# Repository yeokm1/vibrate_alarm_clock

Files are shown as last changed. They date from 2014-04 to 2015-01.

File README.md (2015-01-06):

vibrate_alarm_clock
===================

An alarm clock with vibration and battery monitoring capabilities. During an alarm, it plays the Super Mario tune. Buttons available to set the alarm, turn off OLED and reset. This device is meant for my friend's birthday gift.

The second iteration of this clock can be found [here](https://github.com/yeokm1/vibrate_alarm_clock_2).

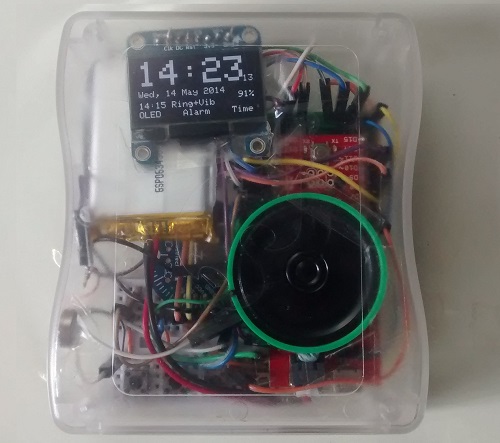
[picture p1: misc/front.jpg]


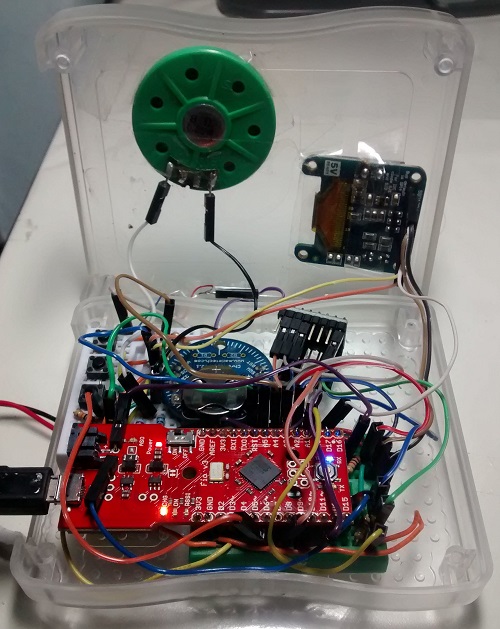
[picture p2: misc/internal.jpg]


I agree this is an epic mess but the space constraints left me no choice. Higher resolution photos are available in the "misc" directory. Battery life is approximately 60 hours based on usage of 16mA with alarm disabled or 38 hours of 26mA with alarm enabled. If the OLED is left on constantly, power use increases to 32mA reducing battery life to 31 hours.  
(See Tips point 3).

<b>Main Parts used:</b>  

1. Sparkfun Arduino Fio V3 (based on ATmega32U4 chip)  
2. Adafruit 1.3" 128x64 OLED set to I2C  
3. Chronodot v2.1 Real Time Clock (based on DS3231 temperature compensated RTC crystal)  
4. 4x button switches (1 switch as reset button)  
5. 3x 10k ohm resistors (for switches)  
6. 8 ohm thin speaker  
7. 100 ohm resistor (for speaker)  
8. 2x 1Mega ohm resistors (as voltage divider to measure battery voltage)
9. Pololu DRV8833 dual motor driver  
10. 10mm vibration motor
11. 1000mAh Lithium battery

Optional:  

1. 2x half-breadboard 
2. Translucent case  

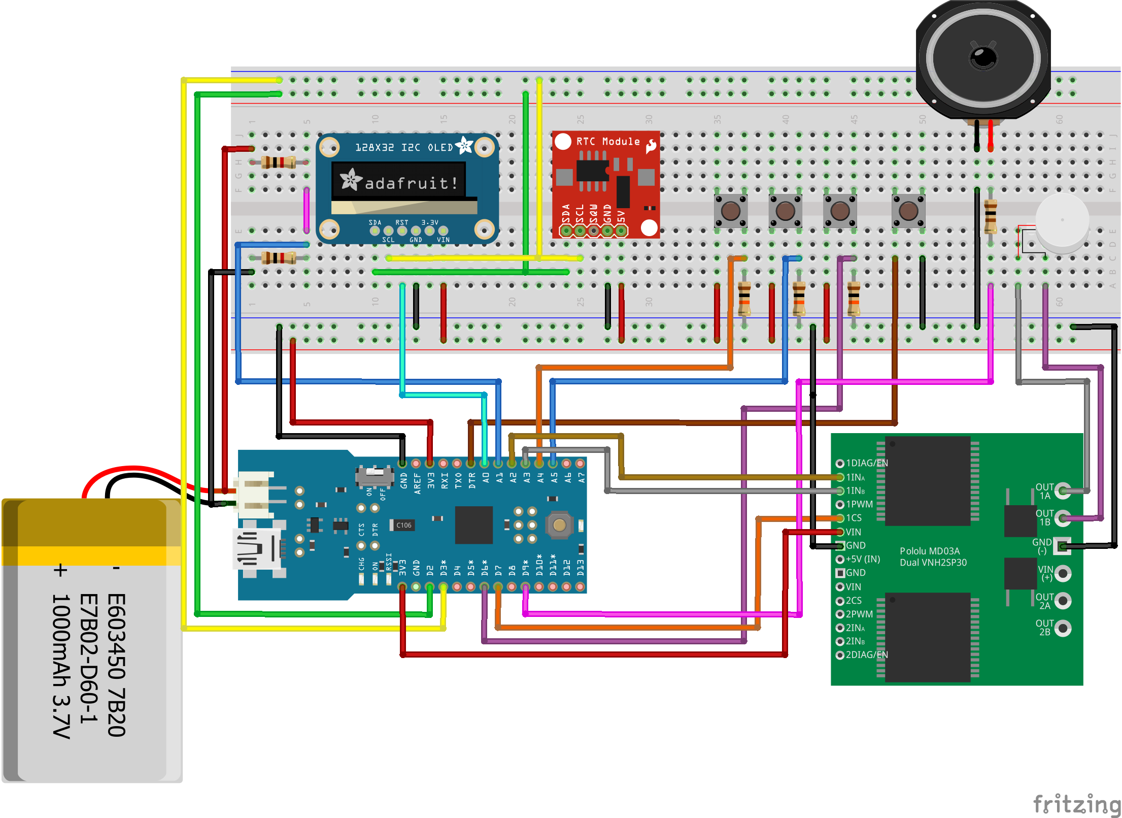
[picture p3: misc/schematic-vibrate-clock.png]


This schematic only represents the logical connections I made. The physical connections differs due to space issues.   
Closest components used as Fritzing does not have them.  
1. MD030A as DRV8833 motor driver. (Pin D7 on the Arduino is connected to the sleep pin on the DRV8833.)  
2. 128x32 OLED as 128x64 OLED.  
3. Fio as Fio V3 (Fio's DTR Pin = Fio V3's RST Pin)  
4. RTC module as Chronodot

<b>Tips:</b>

1. Try to avoid using float variables in your Arduino code if you are tight on binary size. Use integer or long types for intermediate variables if you can.

2. Store unimportant data into flash memory to reduce SRAM usage.

3. Using Rocket Scream's Low Power library works wonders on the Arduino power usage. Standby current use with OLED off is reduced from 26mA to 16mA giving battery life at approximately 60 hours under best case scenario. This advantage disappears once the alarm is enabled. The low power mode somehow prevents the alarm from activating so I have no choice but to disable the low power mode whenever ring or vibrate is enabled. 

<b>Stuff to note:</b>

1. It is possible to set a wrong date and time to the Chronodot. The Chronodot seems to just freeze there? I can check for everything except for the number of days in a month. The extra code to do this check is too much to put into the limited space of the Fio V3. So do be careful when setting the date component.  

2. Included is a subproject named vibrate_alarm_clock_test. This is meant to test all input and output functions.  
  a. On startup, the motor will briefly turn in one then the opposite direction.  
  b. Speaker will play a short tune.  
  c. Pressing first button will rotate motor in one direction until released.  
  d. Pressing second button will rotate motor in another direction until released.  
  e. Pressing both first and second buttons will play the short tune.  
  f. Third button will turn on/off the OLED.  
  g. Since the Arduino IDE only allows included header files to be in the same directory as the .ino, I had to duplicate the constants.h and pitches.h twice. Otherwise, they should be identical and shared between the sub and actual project.

3. The Arduino Fio V3 is quite a finicky thing. Occasionally it will repeatedly refuse to accept code uploads and just disconnect the USB connection. Unplugging/Replugging the USB cable even to another USB port does not work. Pressing the reset button three times before an upload seems to make it work again.

4. The OLED is set by default to use the SPI interface. If you want to use I2C, remember to solder the jumpers at the back. I used I2C to reduce the wire clutter since Chronodot already uses I2C.

5. The OLED library supplied by Adafruit requires at least 1K RAM on the Arduino to buffer the display. The Fio V3 only has 2K so that leaves 1K for other tasks. If you use too much RAM, the OLED may behave strangely like some parts not "rendered".  

6. Super Mario tune is contained in the tune.h header file. To save memory, the tune is stored into flash memory via PROGMEM to minimise SRAM usage.

7. I actually used 2x 220ohm resistors as I did not have a 100ohm resistor. I connected those in parallel to give approximately 100ohm for the speaker.

8. One is supposed to add a pull-up resistor for the I2C bus lines SCL and SDA if more than one device (OLED and Chronodot) uses them. I tried without the resistor and it seems to work fine. 

9. Fio V3's I2C lines are on D2(SDA) and D3(SCL).  

10. The alarm by default lasts for only 10 minutes before automatically turning off to conserve power. Customise this value MAX_ALARM_LENGTH if needed.  

<b>References and libraries:</b>  

1. Adafruit SSD1306 OLED library  
(https://github.com/adafruit/Adafruit_SSD1306)

2. AnyRTC RTClib    
(https://github.com/maniacbug/AnyRtc)

3. Rocket Scream Low Power library  
(http://www.rocketscream.com/blog/2011/07/04/lightweight-low-power-arduino-library/)

4. Get day of week from date.  
(http://stackoverflow.com/a/21235587)

5. Super Mario tune  
(http://www.linuxcircle.com/2013/03/31/playing-mario-bros-tune-with-arduino-and-piezo-buzzer/)

The MIT License (MIT)<br>
Copyright (c) 2014-2014 Yeo Kheng Meng<br>

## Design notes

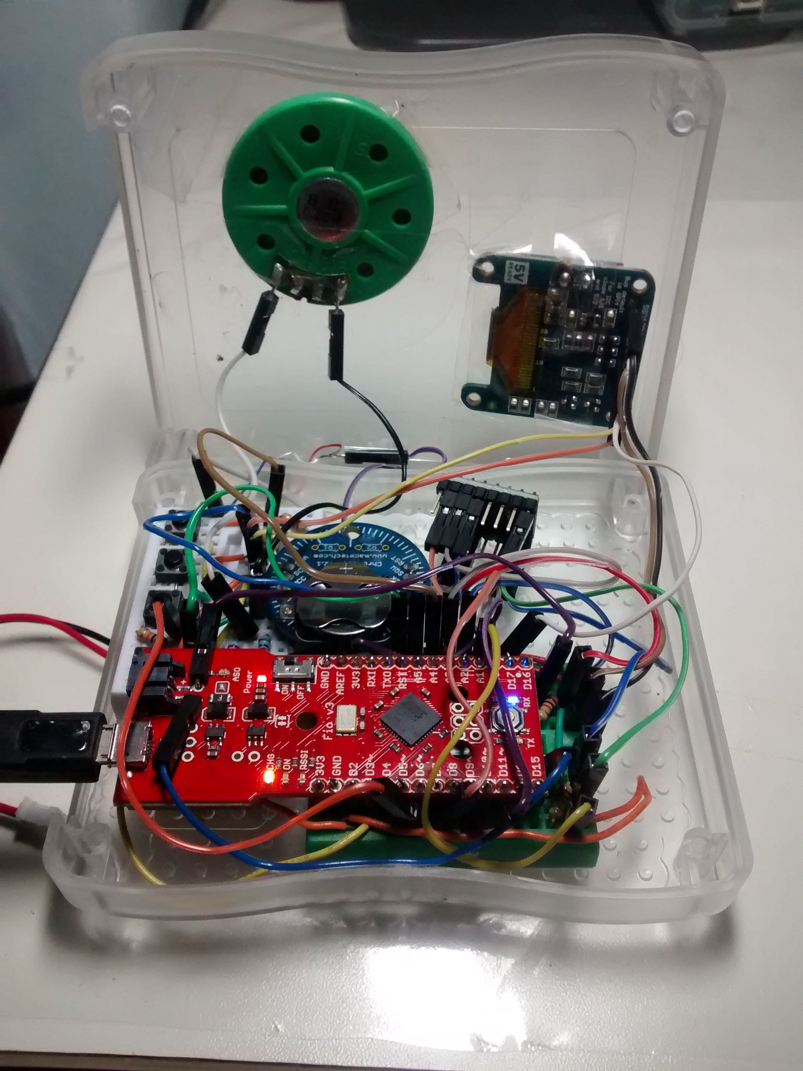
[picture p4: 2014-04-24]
misc/internal-original.jpg

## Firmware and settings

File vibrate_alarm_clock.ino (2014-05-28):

#include <Wire.h>
#include <SPI.h>
#include <Adafruit_GFX.h>
#include <Adafruit_SSD1306.h>
#include <RTClib.h>
#include <RTC_DS1307.h>

#include "LowPower.h"
#include "constants.h"
#include "tune.h"

#define DO_NOT_SHOW_SERIAL_OUT //Comment this line if you want serial debugging for button press

#define MIN_BATTERY_MILLIVOLT 3350 //You may need to calibrate this
#define MAX_BATTERY_MILLIVOLT 4200 //You may need to calibrate this

#define DISPLAY_CONTRAST true

#define INITIAL_TEXT "Happy 24th birthday\n Jason!\n\nBy: Yeo Kheng Meng\n(14 May 2014)"
#define INITIAL_TEXT_DELAY 5000
#define MIN_TIME_BETWEEN_BUTTON_PRESSES 100  //Debouncing purposes
#define BLINK_INTERVAL 100



#define MIN_TIME_BETWEEN_ALARM_STARTS 60000 //60 seconds
#define MIN_TIME_TO_CHANGE_MOTOR_DIRECTION 500

#define MAX_ALARM_LENGTH 600000 //Alarm rings for 10 minutes max

RTC_DS1307 RTC;
Adafruit_SSD1306 display(OLED_RESET_PIN);

typedef enum {NORMAL, ALARM, SETTING_TIME, SETTING_ALARM} CLOCK_STATE ;
CLOCK_STATE currentState = NORMAL;

typedef enum {T_HOUR, T_MINUTE, T_SECOND, T_DAY, T_MONTH, T_YEAR} SETTING_TIME_STATE ;
SETTING_TIME_STATE settingTimeProcess;

typedef enum {A_HOUR, A_MINUTE, A_TYPE} SETTING_ALARM_STATE ;
SETTING_ALARM_STATE settingAlarmProcess;

boolean alarmVibrate = false;
boolean alarmSound = false;

int alarmHour = 07;
int alarmMinute = 00;

unsigned long alarmLastStarted;

typedef enum{M_CLOCKWISE, M_PAUSE} MOTOR_STATE;
MOTOR_STATE lastMotorState;

unsigned long lastVibration;

unsigned long timeLastPressedLeftButton;
unsigned long timeLastPressedMiddleButton;
unsigned long timeLastPressedRightButton;


boolean previousBlinkState;
unsigned long previousBlinkTime;


unsigned long timePlayedPreviousTone;
int toneNow = 0;
int previousNoteDuration;
  
boolean showLCD = true;

void setup(){

  #ifndef DO_NOT_SHOW_SERIAL_OUT
    Serial.begin(9600);
  #endif
  
 //Turn off TX and RX pin
  pinMode(RXLED_PIN, OUTPUT);
  digitalWrite(RXLED_PIN, LOW);
  TXLED1;
  
  Wire.begin();
  RTC.begin();
  

  // This section grabs the current datetime and compares it to
  // the compilation time.  If necessary, the RTC is updated.
  DateTime now = RTC.now();
  DateTime compiled = DateTime(__DATE__, __TIME__);
  
  if (now.unixtime() < compiled.unixtime()) {
    RTC.adjust(DateTime(__DATE__, __TIME__));
  } 
  
  
  // initialize with the OLED with I2C addr 0x3D (for the 128x64)
  display.begin(SSD1306_SWITCHCAPVCC, 0x3D); 
  
  display.dim(DISPLAY_CONTRAST);
  
  display.clearDisplay();
  display.setTextColor(WHITE);
  display.setTextSize(1);
  display.setCursor(0,0);
  display.println(INITIAL_TEXT);
 
  
  display.display();
  
  
  delay(INITIAL_TEXT_DELAY);
  

  pinMode(LEFT_BUTTON_PIN, INPUT); 
  pinMode(MIDDLE_BUTTON_PIN, INPUT); 
  pinMode(RIGHT_BUTTON_PIN, INPUT);
  pinMode(VOLTAGE_MEASURE_PIN, INPUT);
  
  pinMode(MOTOR_PIN1, OUTPUT); 
  pinMode(MOTOR_PIN2, OUTPUT);
  pinMode(MOTOR_SLEEP_PIN, OUTPUT);
  
}


void loop(){
   
 
  int leftButtonState = digitalRead(LEFT_BUTTON_PIN);
  int middleButtonState = digitalRead(MIDDLE_BUTTON_PIN);
  int rightPinState = digitalRead(RIGHT_BUTTON_PIN);

  if(leftButtonState == HIGH){
    processLeftButtonPressed();
  }
  
  if(middleButtonState == HIGH){
    processMiddleButtonPressed();
  }
  
  if(rightPinState == HIGH){
    processRightButtonPressed();
  }
 
  DateTime now = RTC.now();
  

  checkAndSoundAlarm(now.hour(), now.minute());
  soundAlarmAtThisPointIfNeeded();
  
  //Disable alarm if it has gone longer than maximum
  if(currentState == ALARM && (millis() - alarmLastStarted) > MAX_ALARM_LENGTH){
    stopAlarm();
  }
  
  if(showLCD || currentState == ALARM){
    
    display.clearDisplay();

    boolean blinkOn = shouldBlinkNow();
    
   
    int voltageADCReading = analogRead(VOLTAGE_MEASURE_PIN);
     //Multiply 2 as we are are using a half voltage divider
    int batteryMilliVolt = ((long) voltageADCReading * 2 * VOLTAGE_OF_VCC_MV) / ADC_PRECISION;

    writeDateTimeToDisplayBuffer(now, blinkOn);
    writeAlarmToDisplayBuffer(blinkOn);
    writeVoltageToDisplayBuffer(batteryMilliVolt);
    writeButtonStateToDisplayBuffer(blinkOn);
    
    
    display.display();
  }
  
  if((currentState == NORMAL)
  && !alarmSound && !alarmVibrate){
    //Only sleep if no alarm is set. If in other modes like setting, give max performance. 
     LowPower.powerDown(SLEEP_30MS, ADC_OFF, BOD_OFF);

  }
  
}
 
void processLeftButtonPressed(){
  unsigned long currentMillis = millis();
  
  if((currentMillis - timeLastPressedLeftButton) < MIN_TIME_BETWEEN_BUTTON_PRESSES){
    return;
  }
  
  timeLastPressedLeftButton = currentMillis;
  

 #ifndef DO_NOT_SHOW_SERIAL_OUT
   Serial.println("Left Button Press");
 #endif
 
 
  switch(currentState)
  {
  case ALARM: stopAlarm();
  break;
  case NORMAL :
  {
    showLCD = !showLCD;
    turnOffLCD();
    
  }
  break;
  case SETTING_ALARM:
  {
   if(settingAlarmProcess == A_HOUR){
       alarmHour = getNextHourFromCurrentHour(alarmHour, false);
    } else if(settingAlarmProcess == A_MINUTE){
       alarmMinute = getNextMinSecFromCurrentMinSec(alarmMinute, false);
    } else if(settingAlarmProcess == A_TYPE){
              
       if(!alarmVibrate && !alarmSound){
            //Both off, turn on sound
          alarmVibrate = true;
          alarmSound = true;
       } else if(!alarmVibrate && alarmSound){
          //Vibrate off, alarm on, turn on vibrate only
          alarmVibrate = false;
          alarmSound = false;
       } else if(alarmVibrate && !alarmSound){
         //Vibrate on, alarm off, turn on both
         alarmVibrate = false;
         alarmSound = true;  
       } else {
          //Both are on, turn both off
          alarmVibrate = true;
          alarmSound = false;  
      }
   }
  
  }
  break;
  case SETTING_TIME:
  {
    DateTime now = RTC.now();
    DateTime newTime;
    switch(settingTimeProcess){
      case T_HOUR:
        newTime = DateTime(now.year(), now.month(), now.day(), getNextHourFromCurrentHour(now.hour(), false), now.minute(), now.second());
        break;
      case T_MINUTE:
        newTime = DateTime(now.year(), now.month(), now.day(), now.hour(), getNextMinSecFromCurrentMinSec(now.minute(), false), now.second());
        break;
      case T_SECOND:
        newTime = DateTime(now.year(), now.month(), now.day(), now.hour(), now.minute(), getNextMinSecFromCurrentMinSec(now.second(), false));
        break;
      case T_DAY:
        newTime = DateTime(now.year(), now.month(), now.day() - 1, now.hour(), now.minute(), now.second());
        break;
      case T_MONTH:
      {
        int month = now.month();
        if(month == 1){
          month = 12;
        } else {
          month--;
        }
      
        newTime = DateTime(now.year(), month, now.day(), now.hour(), now.minute(), now.second());
      }
        break;
      case T_YEAR:
        newTime = DateTime(now.year() - 1, now.month(), now.day(), now.hour(), now.minute(), now.second());
        break;
      default: break;
     
    }
       
    RTC.adjust(newTime);
  }
  break;
  default: break;
  }
  
  
}

void processMiddleButtonPressed(){
  unsigned long currentMillis = millis();
  

  if((currentMillis - timeLastPressedMiddleButton) < MIN_TIME_BETWEEN_BUTTON_PRESSES){
    return;
  }
  
  timeLastPressedMiddleButton = currentMillis;

 #ifndef DO_NOT_SHOW_SERIAL_OUT
   Serial.println("Middle Button Pressed");
 #endif
   
  switch(currentState)
  {
    case ALARM: stopAlarm();
    break;
    case NORMAL :
    {
      if(showLCD){
        currentState = SETTING_ALARM;
        settingAlarmProcess = A_HOUR;
      } else {
        showLCD = true;
      }

    }
    break;
    case SETTING_ALARM:
    {
      if(settingAlarmProcess == A_HOUR){
         settingAlarmProcess = A_MINUTE;
      } else if(settingAlarmProcess == A_MINUTE){
         settingAlarmProcess = A_TYPE;
      } else {
        currentState = NORMAL;
      }

    }
    break;
    case SETTING_TIME:
    {
      if(settingTimeProcess == T_HOUR){
         settingTimeProcess = T_MINUTE;
      } else if(settingTimeProcess == T_MINUTE){
         settingTimeProcess = T_SECOND;
      } else if(settingTimeProcess == T_SECOND){
         settingTimeProcess = T_DAY;      
      } else if(settingTimeProcess == T_DAY){
        settingTimeProcess = T_MONTH; 
      } else if(settingTimeProcess == T_MONTH){
         settingTimeProcess = T_YEAR;           
      } else {
        currentState = NORMAL;
      }
      
    }
    break;
    default: break;
    }
  


}


void processRightButtonPressed(){
  
  unsigned long currentMillis = millis();
  

  if((currentMillis - timeLastPressedRightButton) < MIN_TIME_BETWEEN_BUTTON_PRESSES){
    return;
  }
   
  timeLastPressedRightButton = currentMillis;

  #ifndef DO_NOT_SHOW_SERIAL_OUT
   Serial.println("Right Set Button Pressed");
  #endif
   
  switch(currentState)
  {
    case ALARM: stopAlarm();
    break;
    case NORMAL :
   { 
      if(showLCD){
        currentState = SETTING_TIME;
        settingTimeProcess = T_HOUR;
      } else {
        showLCD = true;
      }
      
   }
    break;
    case SETTING_ALARM:
    {
        if(settingAlarmProcess == A_HOUR){
          alarmHour = getNextHourFromCurrentHour(alarmHour, true);
        } else if(settingAlarmProcess == A_MINUTE){
          alarmMinute = getNextMinSecFromCurrentMinSec(alarmMinute, true);
        } else if(settingAlarmProcess == A_TYPE){
              
          if(!alarmVibrate && !alarmSound){
                //Both off, turn on sound
                alarmVibrate = false;
                alarmSound = true;
              } else if(!alarmVibrate && alarmSound){
                //Vibrate off, alarm on, turn on vibrate only
                alarmVibrate = true;
                alarmSound = false;
              } else if(alarmVibrate && !alarmSound){
              //Vibrate on, alarm off, turn on both
                alarmVibrate = true;
                alarmSound = true;  
              } else {
                //Both are on, turn both off
                alarmVibrate = false;
                alarmSound = false;  
              }
        }
    }
    break;
    case SETTING_TIME:
      {
    DateTime now = RTC.now();
    DateTime newTime;
    switch(settingTimeProcess){
      case T_HOUR:
        newTime = DateTime(now.year(), now.month(), now.day(), getNextHourFromCurrentHour(now.hour(), true), now.minute(), now.second());
        break;
      case T_MINUTE:
        newTime = DateTime(now.year(), now.month(), now.day(), now.hour(), getNextMinSecFromCurrentMinSec(now.minute(), true), now.second());
        break;
      case T_SECOND:
        newTime = DateTime(now.year(), now.month(), now.day(), now.hour(), now.minute(), getNextMinSecFromCurrentMinSec(now.second(), true));
        break;
      case T_DAY:
        newTime = DateTime(now.year(), now.month(), now.day() + 1, now.hour(), now.minute(), now.second());
        break;
      case T_MONTH:
      {
        int month = now.month();
        if(month == 12){
          month = 1;
        } else {
          month++;
        }
        newTime = DateTime(now.year(), month, now.day(), now.hour(), now.minute(), now.second());
      }
        break;
      case T_YEAR:
        newTime = DateTime(now.year() + 1, now.month(), now.day(), now.hour(), now.minute(), now.second());
        break;
      default: break;
     
    }
       
    RTC.adjust(newTime);
  }
    
    
    break;
    default: break;
  }

}


void writeButtonStateToDisplayBuffer(boolean blinkOn){
  
  String buttonFunction;
  switch(currentState)
  {
    case ALARM: 
    {
      if(!blinkOn){
        buttonFunction = "Stop     Stop    Stop";
      }
    
    }
    break;
    case NORMAL : buttonFunction =  "OLED    Alarm    Time";
    break;
    case SETTING_ALARM: 
    //Fallthrough
    case SETTING_TIME: buttonFunction = "--       Next      ++";
    break;
    default: break;
  }
  
  display.setCursor(0,57);
  display.print(buttonFunction);
 
}


void writeVoltageToDisplayBuffer(int batteryMilliVolt){
  
  display.setTextSize(1);

//  float voltage = (float) batteryMilliVolt / 1000;
  
//  char buff[5];
//  String voltageString = dtostrf(voltage, 3, 1, buff);
// 
//  display.setCursor(104,49);
//  display.print(voltageString);
//  display.print("V");
  
  int batteryRange = MAX_BATTERY_MILLIVOLT - MIN_BATTERY_MILLIVOLT;

  //Cast to long as Arduino int is only 16 bits wide. Not enough to hold this result
  long numerator =  ((long) ((batteryMilliVolt - MIN_BATTERY_MILLIVOLT))) * 100;
  int batteryPercent = numerator / batteryRange;

  if(batteryPercent < 100){
     display.setCursor(110,40);
  } else {
     display.setCursor(104,40);
  }
  display.print(batteryPercent);
  display.print("%");


}

void checkAndSoundAlarm(int hour, int minute){
  
  unsigned long currentMillis = millis();
  
  
  
  if(hour == alarmHour && minute == alarmMinute && currentState == NORMAL
  && ((currentMillis - alarmLastStarted) > MIN_TIME_BETWEEN_ALARM_STARTS)
  && (alarmVibrate || alarmSound)){
    currentState = ALARM;
    alarmLastStarted = currentMillis;
   
   
     if(alarmVibrate){
        lastMotorState = M_CLOCKWISE;
        motorDriverState(true);
     }
  }

}


void soundAlarmAtThisPointIfNeeded(){

  if(currentState == ALARM){
    
    unsigned long currentMillis = millis();

    if(alarmVibrate && ((currentMillis - lastVibration) > MIN_TIME_TO_CHANGE_MOTOR_DIRECTION)){
      lastVibration = currentMillis;
      
      if(lastMotorState == M_CLOCKWISE){
        
        lastMotorState = M_PAUSE;
        changeMotorState(false, false);
      
      } else if(lastMotorState == M_PAUSE){
        
        lastMotorState = M_CLOCKWISE;
        changeMotorState(true, false);
      
      }


    }
    
    if(alarmSound && ((currentMillis - timePlayedPreviousTone) >  previousNoteDuration)){
      timePlayedPreviousTone = currentMillis;
      toneNow++;
      toneNow %= NUM_TONES;
      int noteDuration = 1000/getDurationAtThisPosition(toneNow);
      
      // to distinguish the notes, set a minimum time between them.
      // the note's duration + 30% seems to work well:
      previousNoteDuration = noteDuration * 1.3;
      tone(SPEAKER_PIN, getToneAtThisPosition(toneNow),noteDuration);
      
    }

  }
  
}

void turnOffLCD(){
  if(!showLCD){
    display.clearDisplay();
    display.display();
  }
}

void stopAlarm(){
  currentState = NORMAL;
  motorDriverState(false);
  noTone(SPEAKER_PIN);
  toneNow = 0;
  
  turnOffLCD();
  
}


void writeAlarmToDisplayBuffer(boolean blinkOn){
    
    char buff[3];

    String alarmHourString;
    
    if(currentState == SETTING_ALARM && settingAlarmProcess == A_HOUR && !blinkOn){
     //Now setting this, do not show 
     alarmHourString = "  ";
    } else {
      sprintf(buff, "%02d", alarmHour);
      alarmHourString = buff;
    }
    
    String alarmMinuteString;
    
    if(currentState == SETTING_ALARM && settingAlarmProcess == A_MINUTE && !blinkOn){
     //Now setting this, do not show 
     alarmMinuteString = "  ";
    } else {
      sprintf(buff, "%02d", alarmMinute);
      alarmMinuteString = buff;
    }

    String alarmTimeString;
    String alarmSetting;
       
    if(currentState == SETTING_ALARM && settingAlarmProcess == A_TYPE && !blinkOn){
     //Now setting this, do not show 
     alarmSetting = "";
    } else {
     if(alarmVibrate && alarmSound){
          alarmSetting = " Ring+Vib"; 
      } else if(alarmVibrate){
          alarmSetting = " Vibrate"; 
      } else if(alarmSound){
          alarmSetting = " Ring"; 
      } else {
        alarmSetting = " Alarm Off";
      }
     }

      alarmTimeString = alarmHourString + ":" + alarmMinuteString + alarmSetting;
    
    
    
    
    display.setCursor(0,47);
    display.println(alarmTimeString);

}

void writeDateTimeToDisplayBuffer(DateTime now, boolean blinkOn){
  display.setTextSize(4);
  display.setCursor(0,0);
  String timeString = generateTimeString(now.hour(), now.minute(), now.second(), blinkOn);
  display.print(timeString);
  
  char buff[3];


  if(!(currentState == SETTING_TIME && settingTimeProcess == T_SECOND && !blinkOn)){
    display.setCursor(116,22);
    sprintf(buff, "%02d", now.second());
    display.setTextSize(1);
    display.println(buff);
  }
  

  display.setCursor(0,34);
  display.setTextSize(1);
  String dateString = generateDateString(now.year(), now.month(), now.day(), blinkOn);
  display.println(dateString);

}



String generateTimeString(int hour, int minute, int second, boolean blinkOn){
  char buff[3];
  
  String hourString;
  
  if(currentState == SETTING_TIME && settingTimeProcess == T_HOUR && !blinkOn){
    hourString = "  ";
  } else {
    sprintf(buff, "%02d", hour);
    hourString = buff;
  }

  String minuteString;
  if(currentState == SETTING_TIME && settingTimeProcess == T_MINUTE && !blinkOn){
    minuteString = "  ";
  } else {
    sprintf(buff, "%02d", minute);
    minuteString = buff;
  }


  String result = hourString + ":" + minuteString;

  return result;
}

String generateDateString(int year, int month, int day, boolean blinkOn)
{
  String dayOfWeek = getDayOfTheWeek(year, month, day);
  String dayString;
  String monthString;
  String yearString;
  
  
  if(currentState == SETTING_TIME && settingTimeProcess == T_DAY && !blinkOn){
    dayString = "  ";
  } else {
    char buff[3];
    sprintf(buff, "%02d", day);
    dayString = buff;
  }
  
  if(currentState == SETTING_TIME && settingTimeProcess == T_MONTH && !blinkOn){
    monthString = "   ";
  } else {
    monthString = getMonth(month);
  }
  
  if(currentState == SETTING_TIME && settingTimeProcess == T_YEAR && !blinkOn){
    yearString = "    ";
  } else {
    yearString = String(year);
  }
  
  
 
  String result = dayOfWeek + ", " + dayString + " " + monthString + " " + yearString;
  
  return result;
}

// From http://stackoverflow.com/a/21235587
String getDayOfTheWeek(int y, int m, int d) {
  String weekdayname[] = {"Sun", "Mon", "Tue",
  "Wed", "Thu", "Fri", "Sat"};

  int weekday = (d+=m<3?y--:y-2,23*m/9+d+4+y/4-y/100+y/400)%7;
  
  
  return weekdayname[weekday];
}


String getMonth(int month){
  switch(month){
    case 1: return "Jan";
    case 2: return "Feb";
    case 3: return "Mar";
    
    case 4: return "Apr";
    case 5: return "May";
    case 6: return "Jun";
    
    case 7: return "Jul";
    case 8: return "Aug";
    case 9: return "Sep";
    
    case 10: return "Oct";
    case 11: return "Nov";
    case 12: return "Dec";
    default : return "Nil";
  }
}

void motorDriverState(boolean state){
  if(state){
    digitalWrite(MOTOR_SLEEP_PIN, HIGH);
  } else {
    digitalWrite(MOTOR_SLEEP_PIN, LOW);
  }
}

void changeMotorState(boolean active, bool direction){

  if(!active){
     digitalWrite(MOTOR_PIN1, LOW);
     digitalWrite(MOTOR_PIN2, LOW);
     return; 
  }
  
   if(direction){
     digitalWrite(MOTOR_PIN1, HIGH);
     digitalWrite(MOTOR_PIN2, LOW);     
   } else {
     digitalWrite(MOTOR_PIN1, LOW);
     digitalWrite(MOTOR_PIN2, HIGH); 
   }
    


}

boolean shouldBlinkNow(){
  unsigned long currentMillis = millis();
 
  if(currentMillis - previousBlinkTime >  BLINK_INTERVAL) {
    previousBlinkTime = currentMillis;   
    previousBlinkState = !previousBlinkState;
  }
  return previousBlinkState;
}

int getNextHourFromCurrentHour(int current, boolean increment){
  int change;
  if(increment){
    change = 1;
  } else {
    change = -1;
  }
  
  int newValue = current + change;
  
  //To produce positive modulo result
  return (newValue % 24 + 24) % 24;
}

int getNextMinSecFromCurrentMinSec(int current, boolean increment){
    int change;
  if(increment){
    change = 1;
  } else {
    change = -1;
  }
  
  int newValue = current + change;
  
  //To produce positive modulo result
  return (newValue % 60 + 60) % 60;
}

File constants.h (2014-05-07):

#define LEFT_BUTTON_PIN A4
#define MIDDLE_BUTTON_PIN A5
#define RIGHT_BUTTON_PIN 6 //D6

#define MOTOR_PIN1 A3
#define MOTOR_PIN2 A2
#define MOTOR_SLEEP_PIN 7 //D7

#define SPEAKER_PIN 9 //D9

#define RXLED_PIN 17
#define OLED_RESET_PIN A0

#define VOLTAGE_MEASURE_PIN A1
#define ADC_PRECISION 1024
#define VOLTAGE_OF_VCC_MV 3310 //You may need to calibrate this

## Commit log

2014-04-24 turn off lcd switch
2014-04-24 change motor sleep pin and lcd off pin
2014-04-24 show voltage on screen for test
2014-04-24 LCD off pin
2014-04-24 lcd button switch case
2014-04-24 show voltage and approximate battery left
2014-04-24 design change
    [schematic-vibrate-clock.fzz]
2014-04-24 better schematic
    [schematic-vibrate-clock.fzz]
2014-04-24 don't accept settings buttons when lcd is turned off
2014-04-24 take voltage ADC reading only when lcd is on
2014-04-24 correct bug where cannot stop on alarm when lcd is set to off
    [vibrate_alarm_clock.ino]
2014-04-24 allow three buttons to wake device
2014-05-04 schematic mistake
    [schematic-vibrate-clock.fzz]
2014-05-07 battery percent info shifted up
2014-05-07 print alarm settings in one line
2014-05-07 voltage to 1dp
2014-05-07 button functions
2014-05-07 Button functions shown
2014-05-07 don't print voltage anymore.
2014-05-07 change button var
2014-05-10 allow to set time properly. No error correction on date, it must be set correctly.
    [vibrate_alarm_clock.ino]
2014-05-11 limit month to correct values
    [vibrate_alarm_clock.ino]
2014-05-11 preprocessor directive not to compile serial print code
2014-05-11 display contrast and battery percent improvement
2014-05-11 save power with Low power library
2014-05-11 power down only on normal mode mode
2014-05-12 adjust battery max volt
2014-05-15 pause motor at regular interval. To prevent overheating
    [vibrate_alarm_clock.ino]
2014-05-15 motor interval reduced to 1 second
2014-05-15 change motor direction and pause at regular intervals
2014-05-16 only rotate motor in one direction. Somehow constant changing of direction seems to "jam" it
    [vibrate_alarm_clock.ino]
2014-05-17 wiring error
    [schematic-vibrate-clock.fzz]
2014-05-28 increase min battery voltage
